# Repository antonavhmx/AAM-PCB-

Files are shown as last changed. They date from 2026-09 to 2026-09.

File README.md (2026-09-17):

# 🚀 Sistema Embebido STM32 & PMIC - Diseño PCB de 4 Capas (HDI)

Este repositorio contiene el diseño de hardware y los archivos de manufactura industrial para una tarjeta de circuito impreso de 4 capas. El proyecto se centra en la integración de un microcontrolador de alto rendimiento y gestión de energía, aplicando técnicas de interconexión de alta densidad.

## 📸 Vistas del Proyecto

### Ruteo de Alta Densidad (Layout 2D)
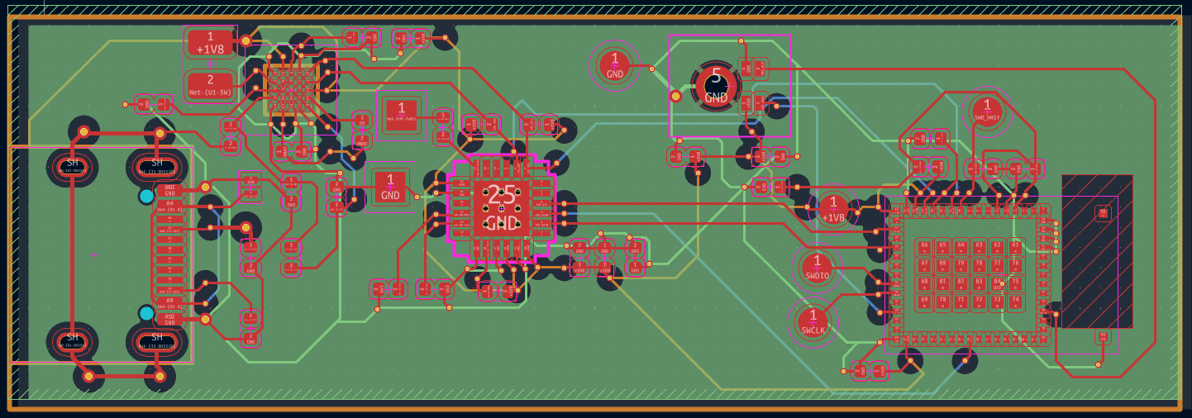
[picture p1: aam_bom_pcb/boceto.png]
Vista 2D del Ruteo

*Detalle del ruteo multicapa mostrando el abanico de salida del BGA, conexiones del PMIC y gestión de tolerancias DRC.*

### Renderizado 3D (Ensamblaje)
**Capa Superior (Top):**
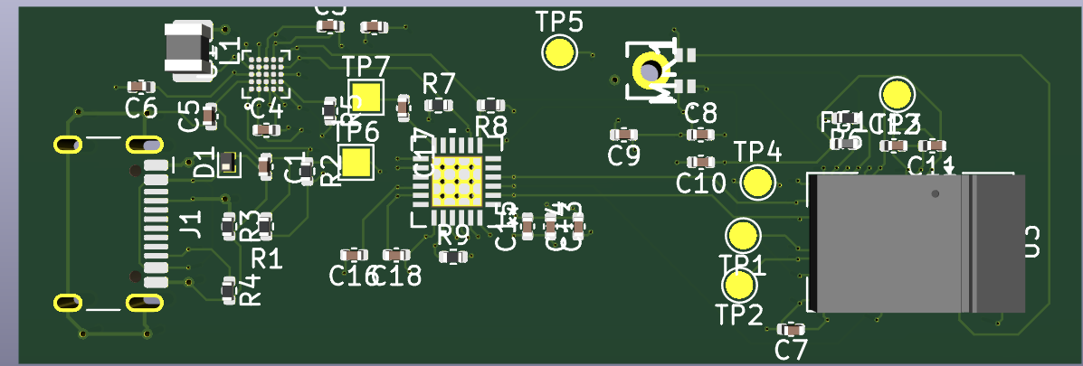
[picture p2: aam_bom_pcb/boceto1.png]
Vista 3D Superior


**Capa Inferior (Bottom):**
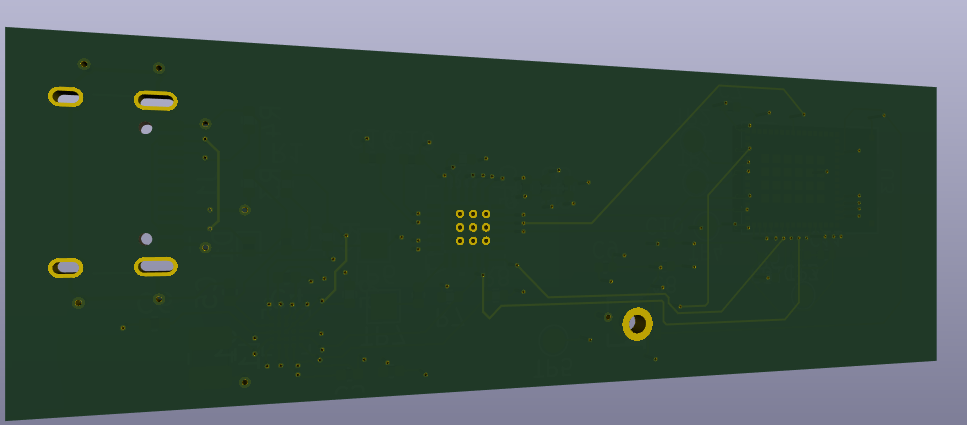
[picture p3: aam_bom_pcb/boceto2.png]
Vista 3D Inferior


## ⚙️ Especificaciones Técnicas

*   **Stackup:** 4 Capas (Capa Superior, Plano GND, Plano VCC, Capa Inferior).
*   **Tecnología HDI:** Implementación de reglas de interconexión de alta densidad para encapsulados complejos.
*   **Procesamiento:** Microcontrolador STM32 en encapsulado BGA.
*   **Gestión de Energía:** PMIC integrado para la regulación eficiente de voltajes.
*   **Reglas de Manufactura (DRC):**
    *   Aplicación estricta de *Via-in-Pad* (0.15mm) para maximizar el espacio y garantizar la integridad de las señales.
    *   Ajuste de impedancias, anchos de pista y aislamientos para asegurar la viabilidad de manufactura sin cortocircuitos.

## 🛠️ Herramientas Utilizadas

*   **KiCad:** Layout de PCB, validación de reglas de diseño (DRC) y generación de visualizaciones 3D.
*   **Git / GitHub:** Control de versiones del hardware y respaldo en la nube del paquete de manufactura.

## 📁 Estructura del Repositorio

*   `/aam_bom_pcb/`: Archivos fuente del proyecto de KiCad (esquemático, PCB, archivos de reglas de diseño).
*   `/gerbers/`: Paquete de manufactura industrial empaquetado (Archivos Gerber X2 y taladros Excellon Drill), validado y listo para fabricación y ensamble (PCBA).

---
## 👥 Créditos y Equipo de Trabajo

Este proyecto de hardware fue desarrollado de manera colaborativa, dividiendo el diseño lógico de la implementación física:

*   **Nava Hernández José Antonio**: Autoría intelectual del proyecto, diseño de la lógica del sistema y captura del esquemático original.
*   **Emilio Severo Bernal López**: Ruteo y layout de la PCB (4 capas con tecnología HDI), validación de reglas de manufactura (DRC) y generación del paquete industrial (Gerber/Drill).

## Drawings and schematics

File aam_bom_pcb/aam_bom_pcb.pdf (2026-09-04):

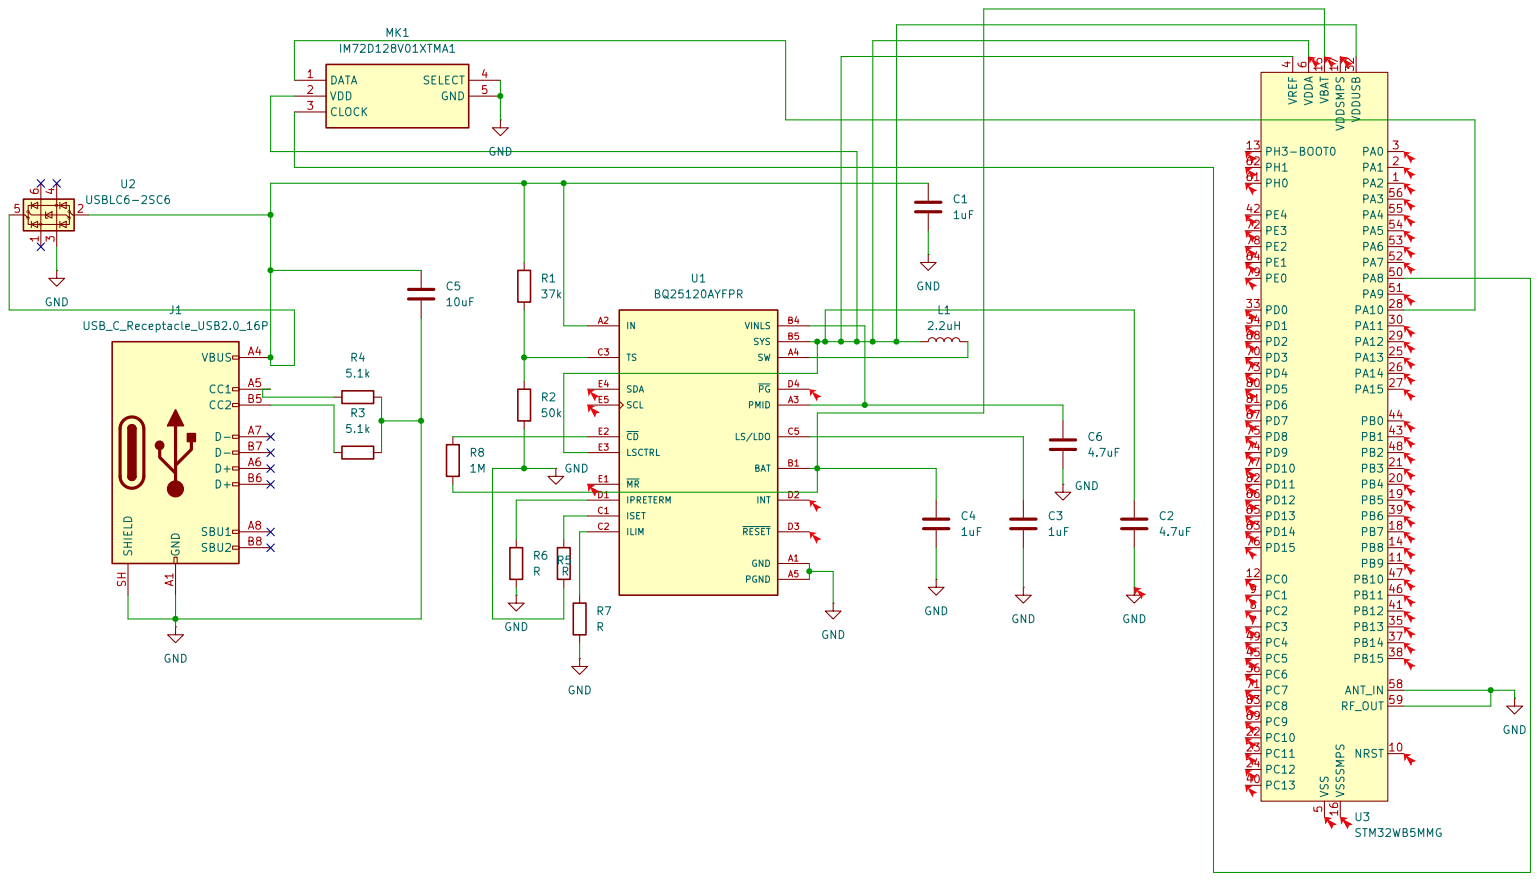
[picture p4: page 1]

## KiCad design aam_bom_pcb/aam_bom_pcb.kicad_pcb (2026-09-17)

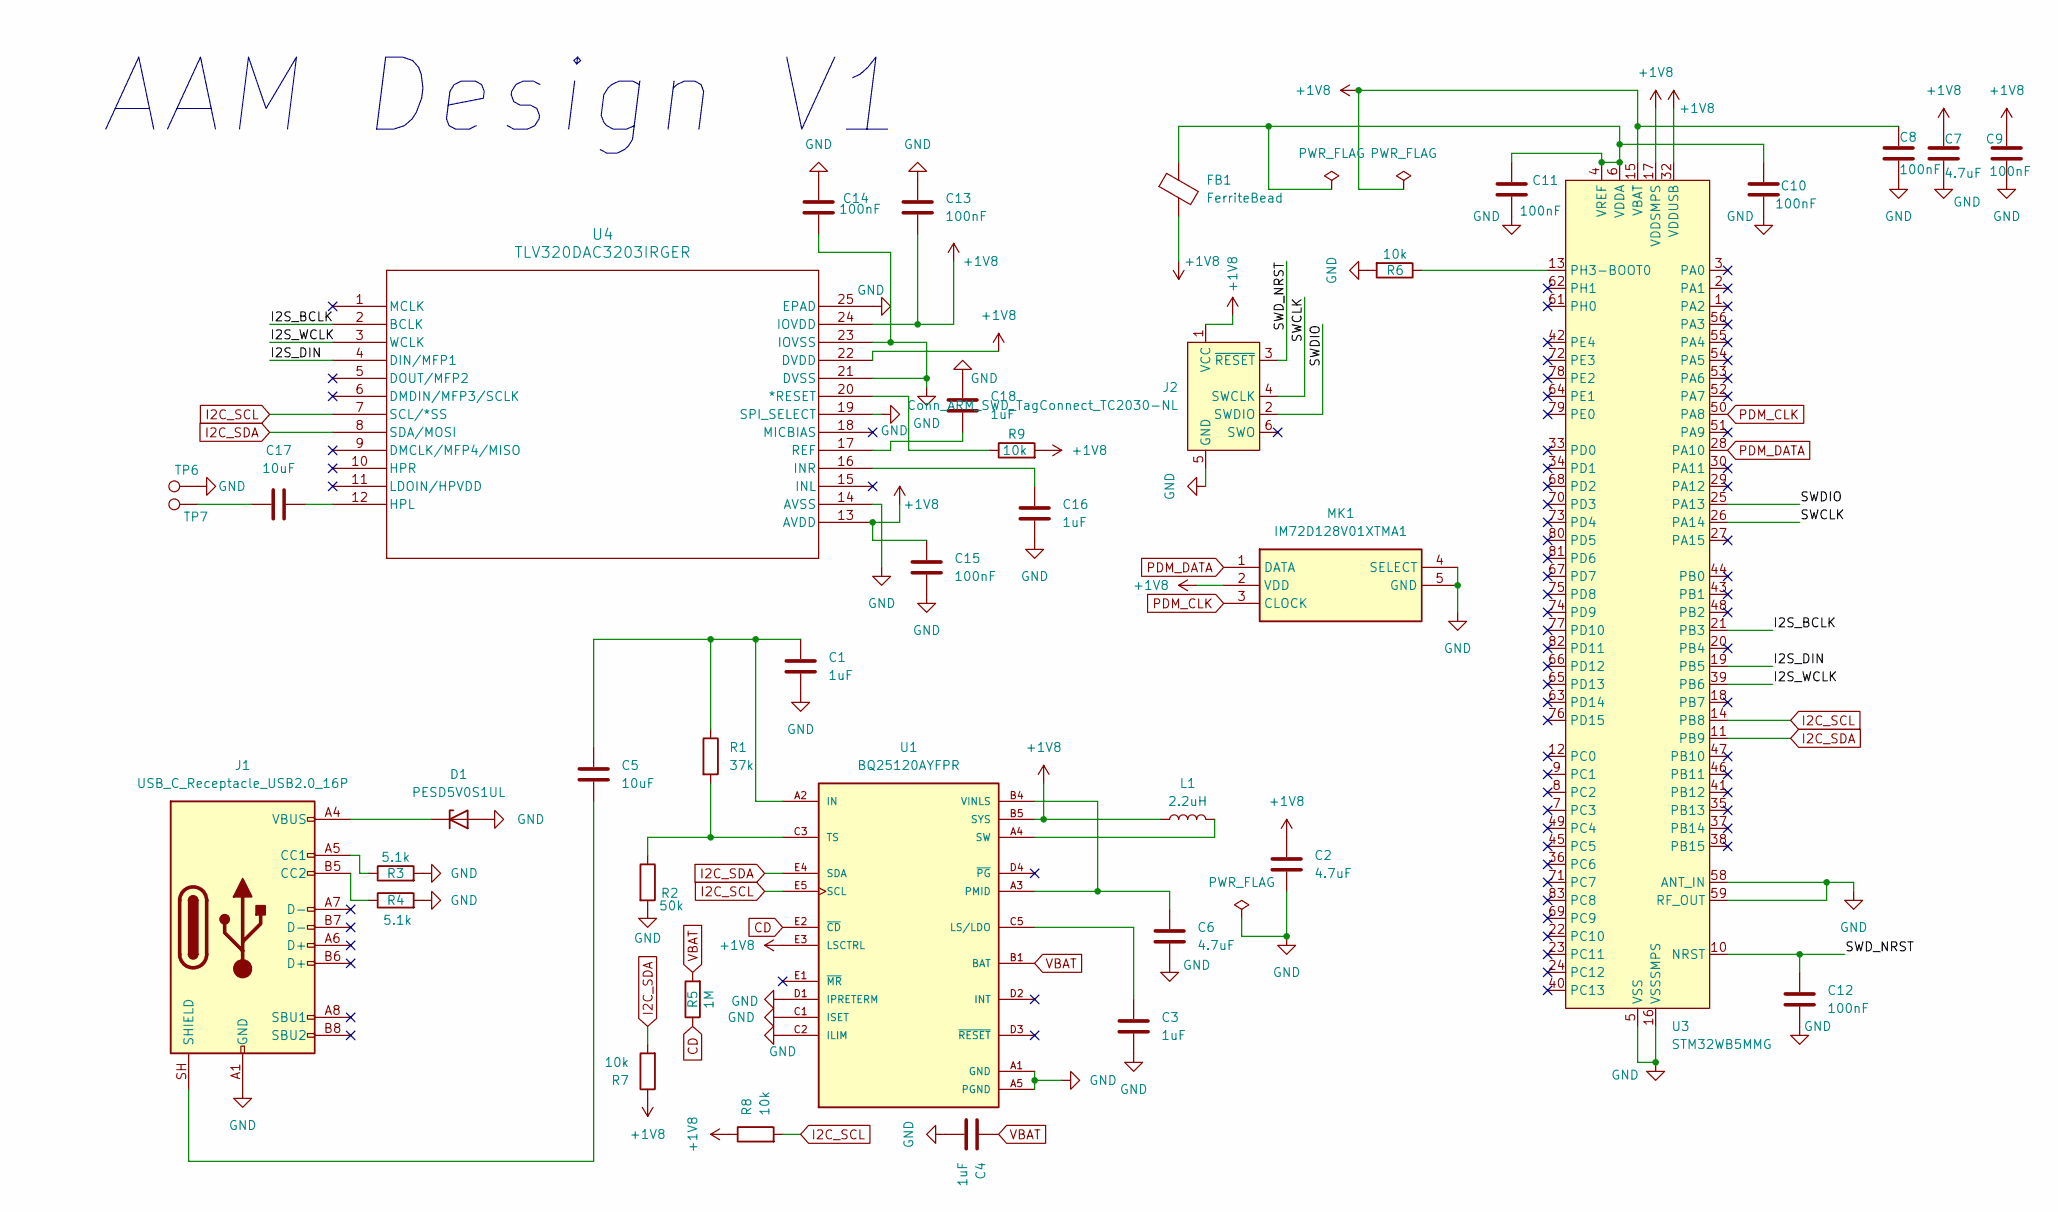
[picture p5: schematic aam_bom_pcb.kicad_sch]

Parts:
C1, C3, C4, C16, C18: 1uF; C_0402_1005Metric
C2, C6, C7: 4.7uF; C_0402_1005Metric
C5, C17: 10uF; C_0402_1005Metric
C8, C9, C10, C11, C12, C13, C14, C15: 100nF; C_0402_1005Metric
D1: PESD5V0S1UL; D_SOD-882
FB1: FerriteBead; L_0402_1005Metric
J1: USB_C_Receptacle_USB2.0_16P; USB_C_Receptacle_HCTL_HC-TYPE-C-16P-01A
J2: Conn_ARM_SWD_TagConnect_TC2030-NL; Tag-Connect_TC2030-IDC-NL_2x03_P1.27mm_Vertical
L1: 2.2uH; L_1008_2520Metric
MK1: IM72D128V01XTMA1; Mouser Part Number 726-IM72D128V01XTMA1
R1: 37k; R_0402_1005Metric
R2: 50k; R_0402_1005Metric
R3, R4: 5.1k; R_0402_1005Metric
R5: 1M; R_0402_1005Metric
R6, R7, R8, R9: 10k; R_0402_1005Metric
TP6, TP7: TestPoint; TestPoint_Pad_1.5x1.5mm
U1: BQ25120AYFPR; IC_BQ25120AYFPR; PARTREV A
U3: STM32WB5MMG; ST-SiP-LGA-86-11x7.3mm
U4: TLV320DAC3203IRGER; RGE24_2P7X2P7_TEX

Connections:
+1V8: C2.1, C7.1, C8.1, C9.1, C13.2, C15.1, FB1.2, J2.1 (VCC), L1.1, MK1.2 (VDD), R7.1, R8.1, R9.2, U1.B5 (SYS), U1.E3 (LSCTRL), U3.15 (VBAT), U3.17 (VDDSMPS), U3.32 (VDDUSB), U4.13 (AVDD), U4.22 (DVDD), U4.24 (IOVDD)
/I2S_BCLK: U3.21 (PB3), U4.2 (BCLK)
/I2S_DIN: U3.19 (PB5), U4.4 (DIN/MFP1)
/I2S_WCLK: U3.39 (PB6), U4.3 (WCLK)
/SWCLK: J2.4 (SWCLK), U3.26 (PA14)
/SWDIO: J2.2 (SWDIO), U3.25 (PA13)
/SWD_NRST: C12.1, J2.3 (~RESET), U3.10 (NRST)
CD: R5.1, U1.E2 (~CD)
GND: C1.2, C2.2, C3.2, C4.2, C6.2, C7.2, C8.2, C9.2, C10.2, C11.2, C12.2, C13.1, C14.1, C14.2, C15.2, C16.2, C18.1, D1.2 (A), J1.A1 (GND), J1.A12 (GND), J1.B1 (GND), J1.B12 (GND), J2.5 (GND), MK1.4 (SELECT), MK1.5 (GND), R2.2, R3.2, R4.2, R6.2, TP6.1 (1_1), U1.A1 (GND), U1.A5 (PGND), U1.C1 (ISET), U1.C2 (ILIM), U1.D1 (IPRETERM), U1.D5 (GND), U3.5 (VSS), U3.16 (VSSSMPS), U3.31 (VSS), U3.57 (VSS), U3.58 (ANT_IN), U3.59 (RF_OUT), U3.60 (VSS), U3.84 (VSS), U3.86 (VSS), U4.14 (AVSS), U4.19 (SPI_SELECT), U4.21 (DVSS), U4.23 (IOVSS), U4.25 (EPAD); also elsewhere on the board
I2C_SCL: R8.2, U1.E5 (SCL), U3.14 (PB8), U4.7 (SCL/*SS)
I2C_SDA: R7.2, U1.E4 (SDA), U3.11 (PB9), U4.8 (SDA/MOSI)
unnamed: C6.1, U1.A3 (PMID), U1.B3 (PMID), U1.B4 (VINLS), U1.C4 (VINLS)
unnamed: C17.1, TP7.1 (1_1)
unnamed: D1.1 (K), J1.A4 (VBUS), J1.A9 (VBUS), J1.B4 (VBUS), J1.B9 (VBUS)
unnamed: J1.A5 (CC1), R3.1
unnamed: J1.B5 (CC2), R4.1
unnamed: C5.2, J1.SH (SHIELD)
unnamed: C1.1, C5.1, R1.1, U1.A2 (IN)
unnamed: C3.1, U1.C5 (LS/LDO)
unnamed: L1.2, U1.A4 (SW)
unnamed: R1.2, R2.1, U1.C3 (TS)
unnamed: R6.1, U3.13 (PH3-BOOT0)
unnamed: C10.1, C11.1, FB1.1, U3.4 (VREF), U3.6 (VDDA)
unnamed: R9.1, U4.20 (*RESET)
unnamed: C17.2, U4.12 (HPL)
unnamed: C16.1, U4.16 (INR)
unnamed: C18.2, U4.17 (REF)
PDM_CLK: MK1.3 (CLOCK), U3.50 (PA8)
PDM_DATA: MK1.1 (DATA), U3.28 (PA10)
VBAT: C4.1, R5.2, U1.B1 (BAT), U1.B2 (BAT)

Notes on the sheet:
AAM Design V1

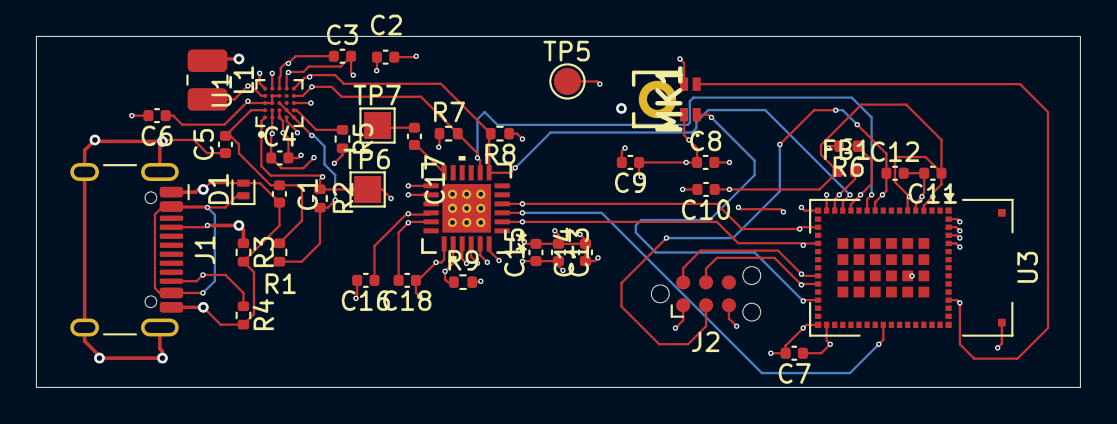
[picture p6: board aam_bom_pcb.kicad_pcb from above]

Board: 4 copper layers, 58.0 x 19.5 mm, 39 parts (0 on the bottom side), 30 nets.

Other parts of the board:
TP5: TestPoint; TestPoint_Pad_D1.5mm

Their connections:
GND: TP5.1 (1_1); also elsewhere on the board

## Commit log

2026-09-14 feat: ruteo 100% y archivos gerber/drill de 4 capas listos
    [aam_bom_pcb-B_Cu.gbr, aam_bom_pcb-B_Mask.gbr, aam_bom_pcb-B_Paste.gbr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]
2026-09-15 Actualización: integración de nuevos archivos al proyecto principal
    [aam_bom_pcb.kicad_pcb]
2026-09-15 Initialize README with project details and specifications
    Added detailed project description, specifications, and tools used for the STM32 embedded system PCB design.
2026-09-15 Update PCB design credit in README
2026-09-15 Revise PCB layout and manufacturing details in README
    Updated PCB layout responsibilities and added details on HDI technology and manufacturing rules.
2026-09-17 Integrar footprint de programación Tag-Connect TC2030-NL y validar esquemático
    [aam_bom_pcb.kicad_pcb, aam_bom_pcb.kicad_sch]
